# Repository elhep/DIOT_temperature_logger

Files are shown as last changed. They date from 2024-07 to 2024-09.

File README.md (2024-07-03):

# temperature-logger
16 channel precision temperature logger with PT100/PT1000 sensors

This piece of equipment was created to make the measurement of PCBs in enclosures possible. The device consists of the base module witch can act in there mode:
- standalone mode using Ethernet communication and powered by PoE, 
- connect to FPGA using DIOT or EEM standard, communicate whit onboard MCU via LVDS line,
- connect to FPGA using DIOT or EEM standard, communicate whit sensors via LVDS line and bypassing the internal MCU controller.
In first two modes data can by log using SD card. Management and configuration are done by USB-C port via Rust consol.

Main module can by connect to the sensors in several ways:
-	directly using screw terminals:  with long VHDCI cable. Length does not matter since the connectivity is with 4 wires
-	with 8 FFC/FPC jumpers. Each jumper supports up to 2 sensors. Jumpers up to 61cm are available
    
The main idea behind using the FFC/FPC jumpers is that they can be easily inserted using enclosure slots and do not affect the airflow.

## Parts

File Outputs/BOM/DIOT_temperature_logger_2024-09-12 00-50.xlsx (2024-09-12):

Manufacturer Part Number | Designator | Quantity | Manufacturer | Footprint | Description
6220 | BAT1 | 1 | VARTA | BAT_VARTA_CR1220 | Battery for use only with Socket Holder
3000 | BATH1 | 1 | KEYSTONE | BATH_KEYSTONE_3000 | Battery Holder whit 2 Pin
CC0805_NO-VALUE | C1, C2, C50, C60, C67, C68, C69, C72 | 8 | Undefined | CAPC2012X135N | Non-polarised capacitor
CC0603_100NF_50V_10%_X7R | C3, C4, C5, C6, C7, C9, C10, C11, C13, C14, C15, C16, C17, C18, C21, C25, C27, C32, C35, C36, C37, C38, C39, C40, C41, C42, C43, C44, C45, C46, C47, C48, C51, C52, C54, C55, C56, C62A, C62B, C62C, C62D, C62E, C62F, C62G, C62H, C62I, C62J, C62K, C62L, C62M, C62N, C62O, C62P, C63A, C63B, C63C, C63D, C63E, C63F, C63G, C63H, C63I, C63J, C63K, C63L, C63M, C63N, C63O, C63P, C65A, C65B, C65C, C65D, C65E, C65F, C65G, C65H, C65I, C65J, C65K, C65L, C65M, C65N, C65O, C65P, C70, C71, C73, C79, C80, C81, C86, C92, C93 | 94 | GENERIC | CAPC1608X87N | Non-polarised capacitor
CC0805_22UF_16V_10%_X5R | C8, C26, C49, C82, C83, C84, C87 | 7 | GENERIC | CAPC2012X135N | Non-polarised capacitor
CC0603_1UF_16V_10%_X7R, CC0603_1UF_25V_10%_X7R | C12, C28, C34, C57, C89 | 5 | GENERIC | CAPC1608X87N | Non-polarised capacitor
CC0603_18PF_50V_5%_NP0 | C19, C20, C59, C61 | 4 | GENERIC | CAPC1608X87N | Non-polarised capacitor
CC0603_12PF_50V_5%_NP0 | C22, C23 | 2 | GENERIC | CAPC1608X87N | Non-polarised capacitor
CC0603_10NF_50V_10%_X7R | C29, C33, C58 | 3 | GENERIC | CAPC1608X87N | Non-polarised capacitor
CC0603_2.2UF_10V_20%_X7R | C30, C31, C64A, C64B, C64C, C64D, C64E, C64F, C64G, C64H, C64I, C64J, C64K, C64L, C64M, C64N, C64O, C64P | 18 | GENERIC | CAPC1608X90N | Non-polarised capacitor
TCJA106M016R0200 | C53, C66A, C66B, C66C, C66D, C66E, C66F, C66G, C66H, C66I, C66J, C66K, C66L, C66M, C66N, C66O, C66P, C85 | 18 | AVX | CAPMP3216X180N | Polarised capacitor
CC1206_4.7NF_500V_10%_X7R | C74, C77, C78 | 3 | GENERIC | CAPC3216X140N | Non-polarised capacitor
CTE7343-43_220UF_16V_10% | C75, C76 | 2 | GENERIC | CAPMP7343X430N | Polarised capacitor
CTE3528-21_2.2UF_25V_10% | C88 | 1 | GENERIC | CAPMP3528X210N | Polarised capacitor
EEEFK1C221AP | C90 | 1 | PANASONIC | CAPAE830X620N | Polarised capacitor
DRTR5V0U4S-7 | D1, D2, D4, D6, D7, D8, D9, D10, D16, D21, D22 | 11 | DIODES | SOT65P210X110-6N | Integrated Quad Ultra-Low Capacitance ESD Protection
CDBU0520-HF | D3, D5, D11 | 3 | COMCHIP | SOD-523F | Schottky Diode
PMEG6020ER | D12, D13, D14, D15, D17, D18, D19, D20, D23, D24, D25, D26, D27, D28, D29 | 15 | NXP SEMICONDUCTORS | SODFL3517X110N | Schottky Diode
SMBJ15A | D30 | 1 | FAIRCHILD SEMICONDUCTOR | DIOM5336X265N | Zener Diode
MF-PSMF050X-2 | F1 | 1 | BOURNS | FUSR_BOURNS_MF-PSMF050 | Fuse
BNX022-01L | FL1 | 1 | MURATA | FIL_MURATA_BNX02 | Block Type EMIFIL (LC Combined)
24AA02E48T-I/OT | IC1, IC2, IC12 | 3 | MICROCHIP TECHNOLOGY | SOT95P280X145-5N | 1.7V-5.5V, 2K I2C Serial EEPROM With EUI-48 Node Identity
FIN1028MX | IC3, IC4, IC7, IC9 | 4 | ON Semiconductor | SOIC127P600X175-8N | 3.3V LVDS 2-Bit High-Speed Differential Reciever
FIN1027AMX | IC5 | 1 | ON Semiconductor | SOIC127P600X175-8N | 3.3V LVDS, 2-Bit, High-Speed, Differential Driver
74HC4066PW | IC6, IC10 | 2 | NXP SEMICONDUCTORS | SOP65P640X110-14N
TLC555ID | IC8 | 1 | TEXAS INSTRUMENTS | SOIC127P600X175-8N | LinCMOS Timer
LM75AIMM | IC11 | 1 | TEXAS INSTRUMENTS | SOP65P490X109-8N | Digital Temperature Sensor and Thermal Watchdog with Two-Wire Interface
STM32H743ZIT6 | IC13 | 1 | STMicroelectronics | FP-LQFP144-1A-MFG | IC MCU 32BIT 2MB FLASH 144LQFP
W25Q128FVSIG | IC14 | 1 | WINBOND | SOIC127P790X216-8N | 128M-bit Serial Flash Memory with uniform 4KB sectors and Dual/Quad SPI and QPI
STM809SWX6F | IC15 | 1 | ST MICROELECTRONICS | SOT95P237X112-3N | 3-Pin Microprocessor Reset Circuit
LAN8742A-CZ | IC16 | 1 | MICROCHIP TECHNOLOGY | MICROCHIP_C04-143B | 10/100 Base-T/TX Ethernet Transceiver with Cable Diagnostics
MAX31865ATP | IC17A, IC17B, IC17C, IC17D, IC17E, IC17F, IC17G, IC17H, IC17I, IC17J, IC17K, IC17L, IC17M, IC17N, IC17O, IC17P | 16 | MAXIM | QFN65P500X500X80-21N-S335 | RTD-to-Digital Converter
74HC138PW | IC18, IC19 | 2 | NXP SEMICONDUCTORS | SOP65P640X110-16N | 3-Line to 8-Line Decoder/Demultiplexer
AG5300 | IC20 | 1 | SILVERTEL | SILVERTEL_AG5300 | Power-over-Ethernet Plus (POE+) Module
ACPL-217-500E | IC21, IC22 | 2 | AVAGO TECHNOLOGIES | SOIC127P700X242-4N | Single Optocoupler
TPS62148RGX | IC23 | 1 | TEXAS INSTRUMENTS | TEXAS_RGX0011A | 3V-17V 2A Step-Down Converter, High Accuracy, With DCS-Control
MIC5219-3.3YM5 | IC24 | 1 | MICROCHIP TECHNOLOGY | SOT95P280X145-5N | 500mA Peak Output LDO Regulator
52745-1097 | J1, J2, J5, J6, J7, J8, J9, J10, J11, J12, J29, J30, J47, J48, J65, J66 | 16 | MOLEX | MOLEX_52745-1097 | Connector 10 Female
71430-0013 | J3, J4, J88 | 3 | MOLEX | MOLEX_71430-0013 | Very High Density Cable Interconnect (VHDCI ) 68 Female
N2530-6002RB | J83 | 1 | 3M | 3M_N2530-6002RB | Connector 30 Male
10052825-101LF | J84 | 1 | AMPHENOL | AMPHENOL_10052825-101LF | 72 Contacts Header, 6 Columns, 4 Pairs per Column
502570-0893 | J85 | 1 | MOLEX | MOLEX_502570-0893 | Connector MicroSD 8 Pin
M50-3600542 | J86 | 1 | HARWIN | HARWIN_M50-3600542 | 10 Contacts - Pitch 1.27mm - Dual Row SMT Vertical Pin Header (Post Lead = 3mm, Insulator 1mm)
5-2337992-3 | J87 | 1 | TE | ABRACON_ARJM11C7-114-BA-EW2 | MagJack 10/100BaseT, PoE+, 1X1, OG/Y, -40 to 85*C, Tab Up, RoHS
KUSBX-SL-CS1N14-B | J89 | 1 | KYCON | KYCON_KUSBX-SL-CS1N14-B | 2x7 Pin + 1 Shield USB Type C Receptacle
39-30-0040 | J90 | 1 | MOLEX | MOLEX_39-30-0040 | Connector 4 Male
 | JP1 | 1 |  | jump | Jumper
BLM18SG221TN1 | L1, L2, L3, L4A, L4B, L4C, L4D, L4E, L4F, L4G, L4H, L4I, L4J, L4K, L4L, L4M, L4N, L4O, L4P, L5 | 20 | MURATA | INDC1608X95N
DLW21SN900SQ2L | L6 | 1 | MURATA | IND_MURATA_DLW21S | Inductor Common Mode
84103C | L7, L9 | 2 | MURATA POWER SOLUTIONS | IND_MURATA-PS_8400 | Inductor With Core
744222 | L8 | 1 | WURTH ELEKTRONIK | IND_WURTH_WE-SL2 | Inductor Common Mode
78439344047 | L10 | 1 | Wurth Elektronik | WE-XHMA_6030 | WE-XHMA SMD Power Inductor, size 6030, 4.7µH, 4.7A, 31mΩ
KPH-1608CGCK | LD1, LD2, LD6, LD7, LD8, LD9, LD10 | 7 | KINGBRIGHT | LED_KINGBRIGHT_KPH-1608CGCK | LED Green 1C 2A
KPH-1608SURCK | LD3 | 1 | KINGBRIGHT | LED_KINGBRIGHT_KPH-1608SURCK | LED Red 1C 2A
H485CHHGGDL | LD4, LD5 | 2 | BIVAR | LED_BIVAR_H485CHHGGDL | LED x4 G-1C2A-BOT_G-3C4A_H-5C6A_H-7C8A-TOP
CS-DSDHD44MF0-002.5 | MECH1 | 1 | Amphenol |  | D-Sub Cables DELUXE HD44 M/F MOLDED 2.5'
691382000004 | P1, P2, P3, P4, P5, P6, P7, P8, P9, P10, P11, P12, P13, P14, P15, P16 | 16 | Wurth Elektronik | 691382000004 | WR-TBL Series 382 Vertical PCB Header, THT, pitch 2.5mm, 4p
830108313809 | Q1 | 1 | Wurth Elektronik | WE-XTAL_CFPX-180 | WE-XTAL Quartz Crystal, SMT, CFPX-180, 8MHz, +/-30ppm
ABS06-32.768kHz-9 | Q2 | 1 | ABRACON | XTAL_ABRACON_ABS06 | Quartz Crystal
8Y-25.000MAAJ-T | Q3 | 1 | TXC CORPORATION | XTAL_TXC_8Y | Crystal 4 pins 1=XTAL Control 2=GND3=XTAL 4=GND
R0603_1K_1%_0.1W_100PPM | R1, R4, R78, R81, R82, R83, R84, R85, R87, R88, R159, R160 | 12 | GENERIC | RESC1608X55N | Resistor - 1%
R0603_0R_JUMPER | R2, R3, R5, R6, R8, R10, R12, R14, R15, R16, R17, R18, R19, R20, R23, R24, R25, R26, R32, R33, R99, R120, R121, R122, R123, R124, R125, R126, R127, R128, R140, R167 | 32 | GENERIC | RESC1608X55N | Resistor
R0603_100R_1%_0.1W_100PPM | R7, R9, R11, R13, R21, R22, R27, R29, R31, R34, R36, R41, R42, R44, R45, R50, R51, R90, R91 | 19 | GENERIC | RESC1608X55N | Resistor - 1%
R0603_10K_1%_0.1W_100PPM | R28, R30, R37, R38, R39, R40, R46, R54, R56, R57, R64, R65, R66, R67, R68, R69, R70, R71, R72, R76, R77, R79, R80, R89, R92, R93, R94, R102, R106, R108, R110, R141, R142, R148, R151, R152, R165, R166 | 38 | GENERIC | RESC1608X55N | Resistor - 1%
R0603_2K7_1%_0.1W_100PPM | R35, R43, R58, R59, R60, R61, R62, R63 | 8 | GENERIC | RESC1608X55N | Resistor - 1%
R0603_33R_1%_0.1W_100PPM | R47, R48, R49, R52, R53, R86, R96, R97, R98, R100, R101, R103, R105, R109 | 14 | GENERIC | RESC1608X55N | Resistor - 1%
R0603_442R_0.1%_0.063W_10PPM | R55, R95, R111, R116A, R116B, R116C, R116D, R116E, R116F, R116G, R116H, R116I, R116J, R116K, R116L, R116M, R116N, R116O, R116P, R144 | 20 | GENERIC | RESC1608X55N | Resistor - 0.1%
R0603_10M_1%_0.1W_100PPM | R73, R74, R119A, R119B, R119C, R119D, R119E, R119F, R119G, R119H, R119I, R119J, R119K, R119L, R119M, R119N, R119O, R119P | 18 | GENERIC | RESC1608X55N | Resistor - 1%
R0603_12K1_0.1%_0.063W_10PPM | R104, R155, R156, R157, R158 | 5 | GENERIC | RESC1608X55N | Resistor - 0.1%
R0603_1K5_1%_0.1W_100PPM | R107 | 1 | GENERIC | RESC1608X55N | Resistor - 1%
R0603_49K9_1%_0.1W_100PPM | R112, R113, R114, R115, R154 | 5 | GENERIC | RESC1608X55N | Resistor - 1%
R0603_22K_0.1%_0.1W_25PPM | R117A, R117B, R117C, R117D, R117E, R117F, R117G, R117H, R117I, R117J, R117K, R117L, R117M, R117N, R117O, R117P, R139, R146, R149 | 19 | GENERIC | RESC1608X64N | Resistor - 0.1%
R0603_3K92_0.1%_0.063W_10PPM | R118A, R118B, R118C, R118D, R118E, R118F, R118G, R118H, R118I, R118J, R118K, R118L, R118M, R118N, R118O, R118P | 16 | GENERIC | RESC1608X55N | Resistor - 0.1%
R0603_5K1_1%_0.1W_100PPM | R137, R138 | 2 | GENERIC | RESC1608X55N | Resistor - 1%
R0603_82K_1%_0.1W_100PPM | R143, R145, R150 | 3 | GENERIC | RESC1608X55N | Resistor - 1%
R0805_10R_1%_0.125W_200PPM | R147 | 1 | GENERIC | RESC2012X60N | Resistor - 1%
R0603_38K3_0.1%_0.063W_10PPM | R153 | 1 | GENERIC | RESC1608X55N | Resistor - 0.1%
20818-017 | ST1 | 1 | Schroff | SCHROFF_PANEL_3HP_4U - Thermostat | Schroff 3HP 4U EUROCARD Panel
A6SN-1101 | SW1A, SW1B, SW1C, SW1D, SW1E, SW1F, SW1G, SW1H, SW1I, SW1J, SW1K, SW1L, SW1M, SW1N, SW1O, SW1P | 16 | OMRON | SW_OMRON_A6SN-1101 | 1 Ways SPST DIP Switch
BSS138L | T1, T2, T4, T5, T6, T7 | 6 | ON SEMICONDUCTOR | SOT95P240X110-3N | N-CHANNEL MOSFET WITH DIODE
FDN86246 | T3 | 1 | ON SEMICONDUCTOR | SOT95P237X112-3N | N-CHANNEL MOSFET WITH DIODE
HTSW-104-23-L-S | W2 | 1 | SAMTEC | SAMTEC_HTSW-104-23-L-S | 4 Mini Wire-Wrap Contact Strip Header

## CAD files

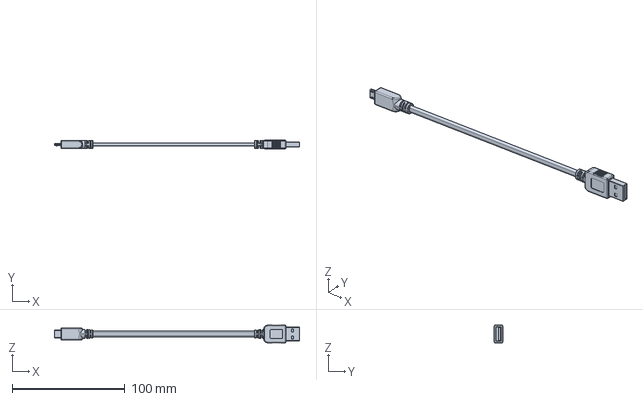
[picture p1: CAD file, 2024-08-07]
doc/10133304-001lfc.stp
217.6 x 7.60 x 15.7 mm

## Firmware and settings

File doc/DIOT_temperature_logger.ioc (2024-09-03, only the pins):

Mcu.UserName=STM32H743ZITx
PA1.Signal=ETH_REF_CLK
PA10.Signal=USB_OTG_FS_ID
PA11.Signal=USB_OTG_FS_DM
PA12.Signal=USB_OTG_FS_DP
PA2.Signal=ETH_MDIO
PA3.GPIO_Label=POE_PWR_SRC
PA3.Signal=GPIO_Output
PA4.Signal=SPI1_NSS
PA5.Signal=SPI1_SCK
PA6.Signal=SPI1_MISO
PA7.Signal=ETH_CRS_DV
PA8.Signal=RCC_MCO_1
PA9.Signal=USB_OTG_FS_VBUS
PB0.GPIO_Label=EEM_GPIO_2
PB0.Signal=GPIO_Output
PB1.GPIO_Label=EEM_GPIO_3
PB1.Signal=GPIO_Output
PB10.Signal=SPI2_SCK
PB12.Signal=SPI2_NSS
PB14.Signal=SPI2_MISO
PB15.Signal=SPI2_MOSI
PB2.GPIO_Label=BOOT1
PB2.Signal=GPIO_Input
PB5.Signal=SPI1_MOSI
PB6.Signal=USART1_TX
PB7.Signal=USART1_RX
PB8.Signal=I2C1_SCL
PB9.Signal=I2C1_SDA
PC0.GPIO_Label=U_meas_P12V0
PC0.Signal=ADCx_INP10
PC1.Signal=ETH_MDC
PC10.Signal=SDMMC1_D2
PC11.Signal=SDMMC1_D3
PC12.Signal=SDMMC1_CK
PC2_C.GPIO_Label=U_meas_P3V3
PC2_C.Signal=ADC3_INP0
PC4.Signal=ETH_RXD0
PC5.Signal=ETH_RXD1
PC8.Signal=SDMMC1_D0
PC9.Signal=SDMMC1_D1
PD2.Signal=SDMMC1_CMD
PD3.GPIO_Label=SD_SW
PD3.Signal=GPIO_Input
PE11.Signal=SPI4_NSS
PE12.Signal=SPI4_SCK
PE13.Signal=SPI4_MISO
PE14.Signal=SPI4_MOSI
PF0.Signal=I2C2_SDA
PF1.Signal=I2C2_SCL
PF10.Signal=QUADSPI_CLK
PF12.Signal=ADC1_INP6
PF13.Signal=ADC2_INP2
PF14.Signal=I2C4_SCL
PF15.Signal=I2C4_SDA
PF6.Signal=QUADSPI_BK1_IO3
PF7.Signal=QUADSPI_BK1_IO2
PF8.Signal=QUADSPI_BK1_IO0
PF9.Signal=QUADSPI_BK1_IO1
PG0.GPIO_Label=EEM_GPIO_0
PG0.Signal=GPIO_Output
PG1.GPIO_Label=EEM_GPIO_1
PG1.Signal=GPIO_Output
PG11.Signal=ETH_TX_EN
PG12.Signal=ETH_TXD1
PG13.Signal=ETH_TXD0
PG6.Signal=QUADSPI_BK1_NCS

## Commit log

2024-07-03 add schematic file for review
    [Adapters.SchDoc, Breakout.SchDoc, DIOT_temperature_logger.PrjPCB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]
2024-07-03 minor chaneg
    [FrontPanel.PcbDoc]
2024-07-09 Ideal diode replace to schottky diod Add R0 jumper to &4HC138PW Add i2c to VHDCI connector and eeprom at the end of cabel, Add RTC battery (CR2032)
    [Adapters.SchDoc, Breakout.SchDoc, EEM_DIOT_connector.SchDoc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]
2024-07-15 Schematic and component placement update
    [Adapters.SchDoc, DIOT_temperature_logger.PrjPCB, EEM_DIOT_connector.SchDoc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]
2024-07-18 Placment and Layout update
    [EEM_DIOT_connector.SchDoc, MCU_STM32F4.SchDoc, RTD.SchDoc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]
2024-07-25 Sch and layout update
    [Adapters.SchDoc, DIOT_temperature_logger.PrjPCB, EEM_DIOT_connector.SchDoc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]
2024-08-01 Layout > 60%
    [Adapters.SchDoc]
2024-08-07 Layer stack change: -TOP, BOT signal power, -MID1, MID2 gnd, Add impedance and length control rules to project for nets RMII, SD, QSPI, USB, LVDS, BP_IO
    [10133304-001lfc.stp, Bill of Materials-DIOT_temperature_logger(Default).xlsx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]
2024-08-07 Layout update
    [MCU_STM32F4.SchDoc]
2024-08-09 save state - in the middle of rebuild
    [Bill of Materials-DIOT_temperature_logger(Default).xlsx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]
2024-08-23 100% layout commit, major layout and placment change
    [Adapters.SchDoc, DIOT_temperature_logger.PrjPCB, DIOT_temperature_logger.SCHLIB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]
2024-08-23 100% layput, 100% DRC
    [Adapters.SchDoc, DIOT_temperature_logger.PrjPCB, EEM_DIOT_connector.SchDoc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]
2024-08-23 file claen up
    [Bill of Materials-DIOT_temperature_logger(Default).xlsx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]
2024-08-23 Release candidate, Need to add: copper balancing, terdrop etc.
    [Adapters.SchDoc, DIOT_temperature_logger.PrjPCB, EEM_DIOT_connector.SchDoc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]
2024-08-24 minor layout twick, add slik screan RTD chanal naming
    [Adapters.SchDoc, DIOT_temperature_logger.PrjPCB, EEM_DIOT_connector.SchDoc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]
2024-08-24 add front panel
    [FrontPanel DIOT_Temperature_logger.PcbDoc]
2024-08-29 in the middle of rework
    [DIOT_temperature_logger.PrjPCB, EEM_DIOT_connector.SchDoc, Supply.schdoc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]
2024-09-01 100% connection after rework
    [DIOT_temperature_logger.PrjPCB]
2024-09-03 release candidate no.1
    [DIOT_temperature_logger.PrjPCB, MCU_STM32F4.SchDoc, Supply.schdoc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]
2024-09-08 secend issiue list apply
    [Adapters.SchDoc, RMII_Ethernet.SchDoc, Supply.schdoc]
2024-09-08 release candidate no.2
    [Adapters.SchDoc, MCU_STM32F4.SchDoc, Supply.schdoc]
2024-09-08 release candidate no.3
    [MCU_STM32F4.SchDoc, RMII_Ethernet.SchDoc]
2024-09-10 Release candidate No.4
    [DIOT_temperature_logger.PrjPCB, MCU_STM32F4.SchDoc, Thermostat_16CH.SchDoc]
2024-09-12 Final release V1.0
    [Adapters.SchDoc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]
